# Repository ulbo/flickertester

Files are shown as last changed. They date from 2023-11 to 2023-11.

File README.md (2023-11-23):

# flickertester
Using RaspberryPi Pico to visualize flicker of LED lamps

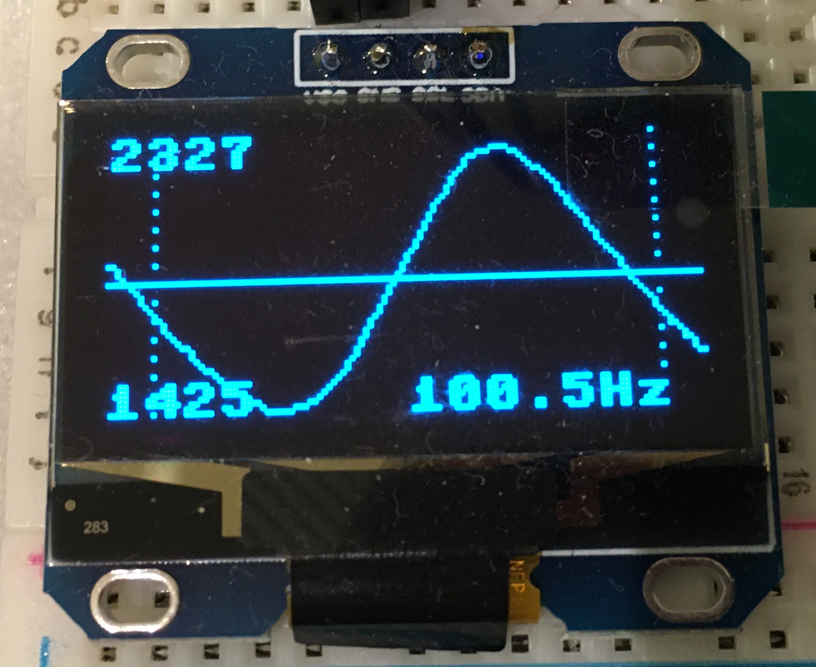
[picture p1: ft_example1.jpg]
Example


A small project for visualizing the flicker of LED lamps on a display. On the left side the minimum and maximum measured brightness value is shown, on the lower right side the calculated flicker frequency in Hertz.

Implementation is done in MicroPython on a RaspberryPi Pico using a CJMCU breakout board for the OPT101 light sensor and a SH1106 OLED display; both are available in the usual maker shops.

The analogue output value of the OPT101 is digitized by the Pico which shows the waveform on the display. Implementation is quite crude; more a proof-of-concept than a "real" device.

**Circuit**
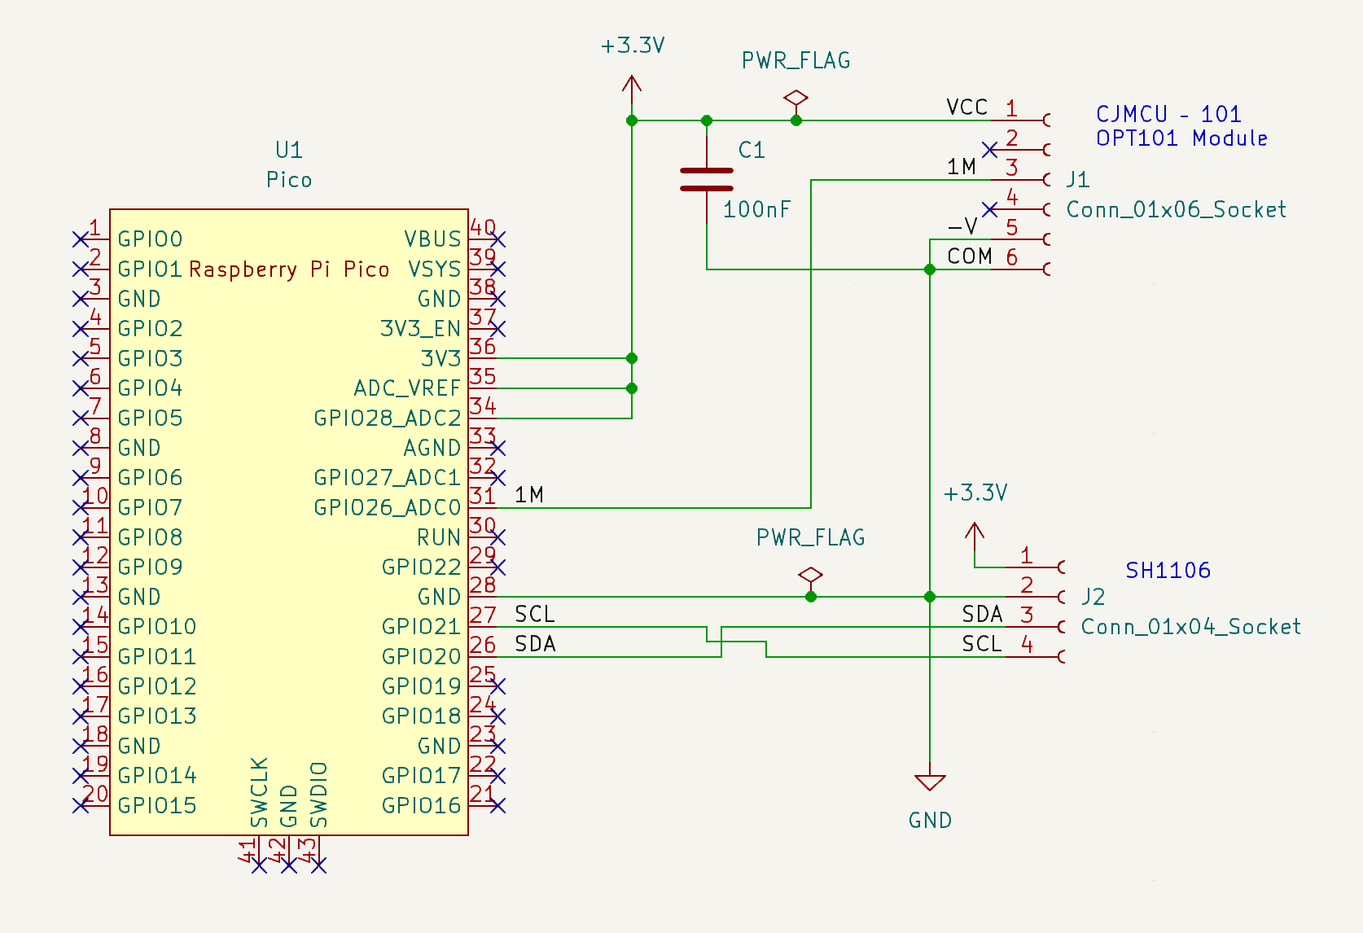
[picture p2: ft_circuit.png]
Circuit


**Breadboard**
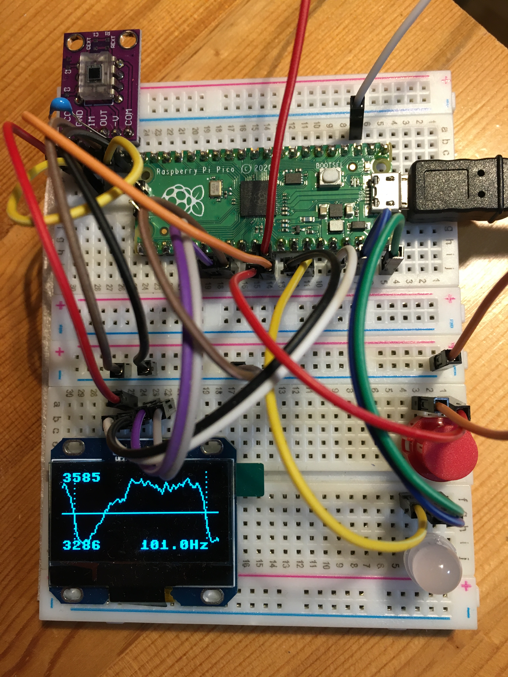
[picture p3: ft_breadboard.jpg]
Breadboard circuit


**References**

SH1106 driver: https://github.com/robert-hh/SH1106

OPT101 circuit: https://www.electroschematics.com/photodiode/

DMA code borrowed from https://iosoft.blog/2021/10/26/pico-adc-dma/

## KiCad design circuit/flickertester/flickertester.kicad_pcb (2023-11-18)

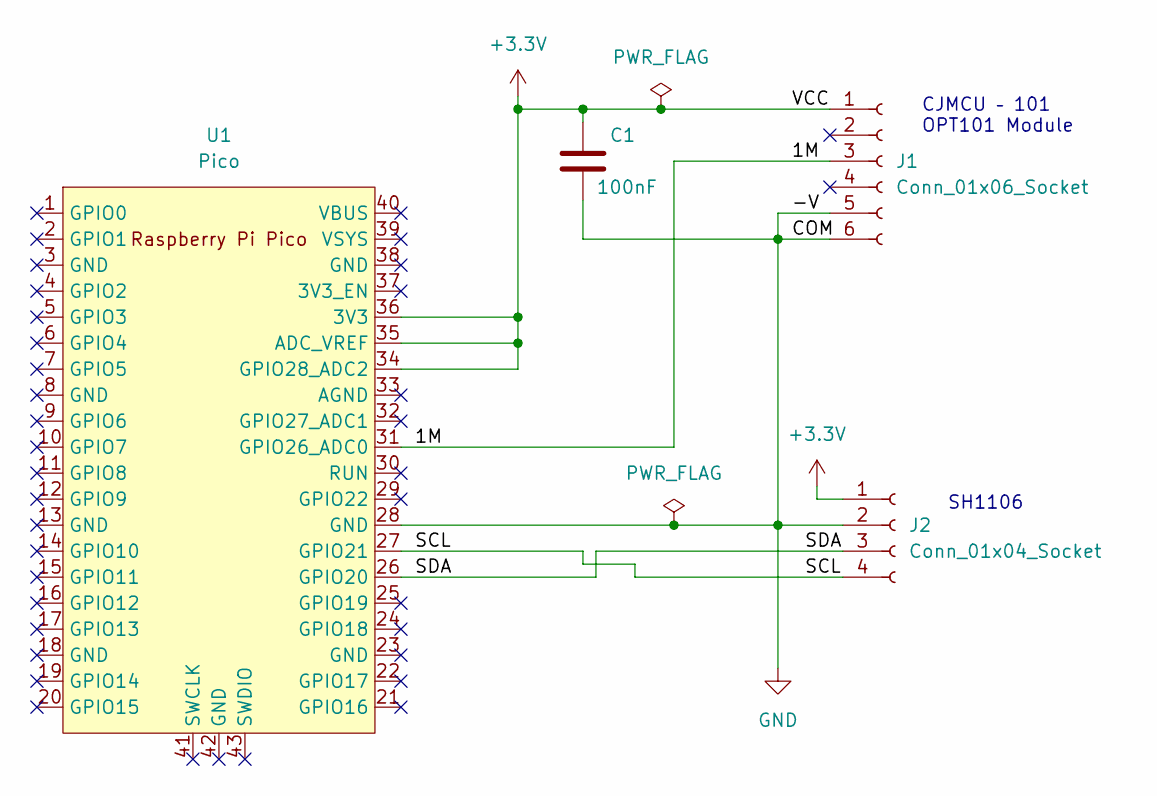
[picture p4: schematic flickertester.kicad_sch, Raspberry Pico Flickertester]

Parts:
C1: 100nF; CP_Radial_D5.0mm_P2.50mm
J1: Conn_01x06_Socket; PinSocket_1x06_P2.54mm_Vertical
J2: Conn_01x04_Socket; PinSocket_1x04_P2.54mm_Vertical
U1: Pico; RPi_Pico_SMD_TH

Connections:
+3.3V: C1.1, J1.1, J2.1, U1.34 (GPIO28_ADC2), U1.35 (ADC_VREF), U1.36 (3V3)
/1M: J1.3, U1.31 (GPIO26_ADC0)
/SCL: J2.4, U1.27 (GPIO21)
/SDA: J2.3, U1.26 (GPIO20)
GND: C1.2, J1.5, J1.6, J2.2, U1.28 (GND)

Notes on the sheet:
SH1106
CJMCU – 101 OPT101 Module

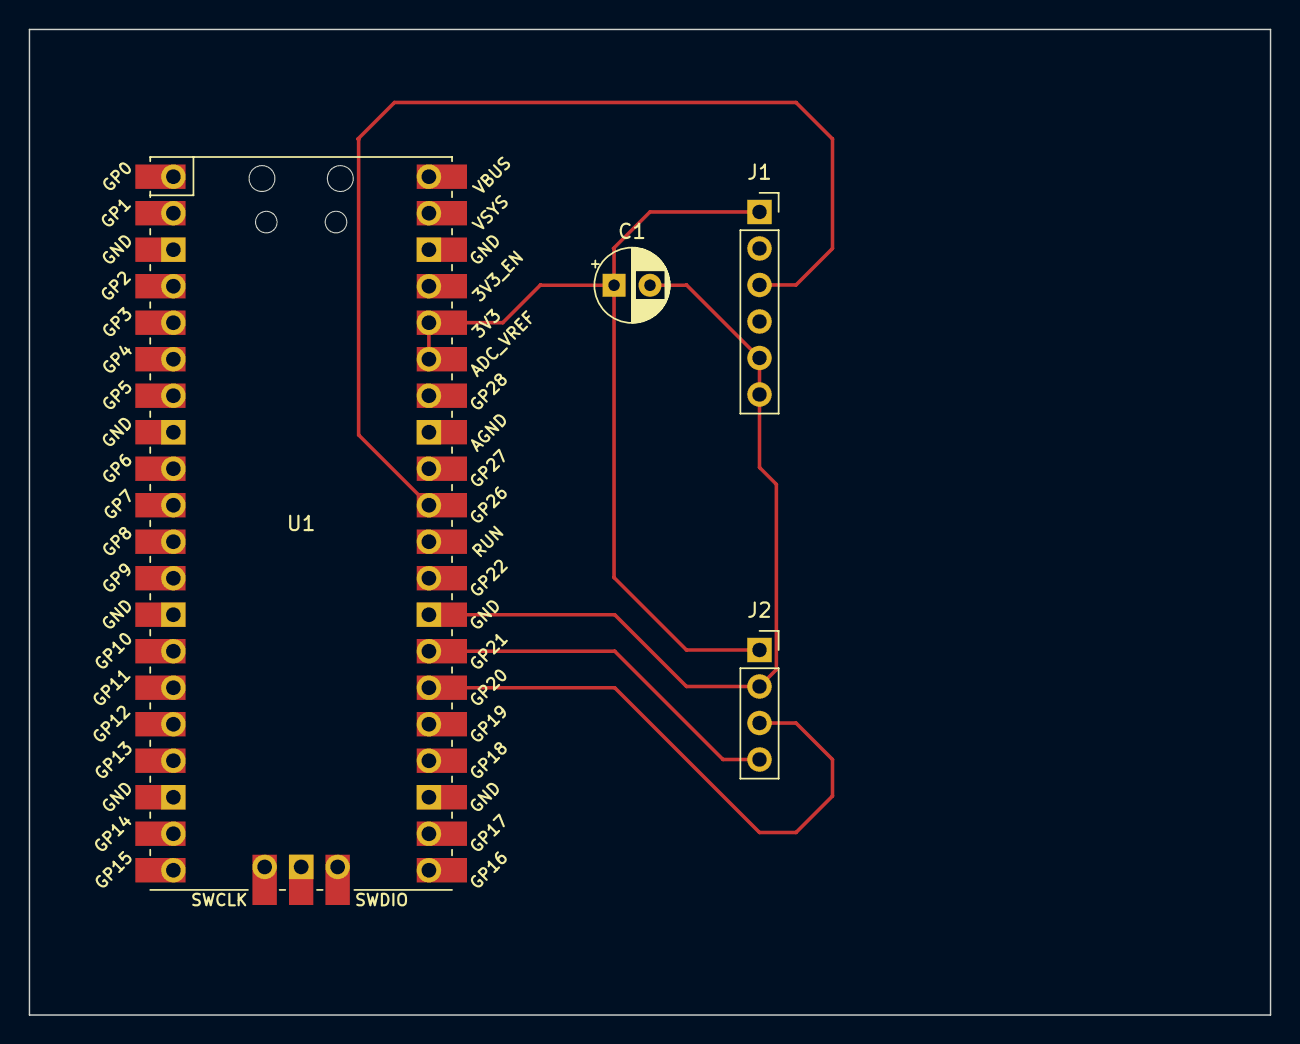
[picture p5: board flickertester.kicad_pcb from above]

Board: 2 copper layers, 86.4 x 68.6 mm, 4 parts (0 on the bottom side), 5 nets.

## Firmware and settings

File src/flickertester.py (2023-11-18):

# Display flicker curve on I2C driven SH1106 OLED display
#
# Platform: MicroPython on Raspberry Pico
# Photodiode: OPT101 (for circuit see https://www.electroschematics.com/photodiode/)
# Display: SH1106 OLED display
#
# OPT101/ADC characteristics: Min: 0V / 300 digits
#                             Max: 2.5V / 3100 digits
#
# Libraries: SH1106 driver from https://github.com/robert-hh/SH1106

from machine import I2C, ADC, Pin
from sh1106 import SH1106_I2C
import framebuf
import time, array, uctypes, rp_devices as devs

SCREEN_WIDTH  = 128         # OLED display width
SCREEN_HEIGHT = 64          # OLED display height

NSAMPLES = 1200             # number of samples taken from ADC
SAMPLING_RATE = 20000       # ADC sampling rate

# =====================================================================
# Helper functions for display graphics
# ---------------------------------------------------------------------
def pset(x: int, y: int, col:int):
    """Set pixel with upright coordinate system"""
    # pyxel.pset(x, SCREEN_HEIGHT - y, col)
    oled.pixel(x, y, 1)

# ---------------------------------------------------------------------
def line(x1: int, y1: int, x2: int, y2: int, col:int):
    """Draw line with upright coordinate system"""
    # pyxel.line(x1, SCREEN_HEIGHT - y1, x2, SCREEN_HEIGHT - y2, col)
    oled.line(x1, y1, x2, y2, 1)

# ---------------------------------------------------------------------
def vline_dot(x: int):
    "Draw a vertical dotted line"
    for y in range(0, SCREEN_HEIGHT, 4):
        oled.pixel(x, y, 1)

# ---------------------------------------------------------------------
def text(x: int, y: int, s: str, col:int):
    # pyxel.text( x, SCREEN_HEIGHT - y, s, col)
    oled.text(s, int(x), int(y))


# =====================================================================
# OLED functions
# ---------------------------------------------------------------------
# Init I2C using given Pins
def init_i2c():
    i2c = I2C(0, sda=Pin(20), scl=Pin(21), freq=400000)

    print("I2C Address      : "+hex(i2c.scan()[0]).upper()) # Display device address
    print("I2C Configuration: "+str(i2c))                   # Display I2C config
    return i2c

# ---------------------------------------------------------------------
def init_oled(i2c):
    oled = SH1106_I2C(SCREEN_WIDTH, SCREEN_HEIGHT, i2c)     # Init oled display

    # Clear the oled display in case it has junk on it.
    oled.fill(0)

    # Display is built-in upside down
    oled.flip()
    return oled

# ---------------------------------------------------------------------
def oled_demo():
    """Just to test OLED functions"""
    # Add some text
    oled.text("Raspberry Pi",5,5)
    oled.text("Pico",5,15)

    # draw something
    for i in range(5, 120, 2):
        oled.pixel(i, 50, 1)

    w = SCREEN_WIDTH-1
    h = SCREEN_HEIGHT-1

    oled.line(0, 0, w, h, 1)
    oled.line(0, h, w, 0, 1)
    x = int(w / 2)
    y = int(h / 2)
    oled.ellipse(x, y, x, y, 1)

    # Finally update the oled display so the image & text is displayed
    oled.show()

# =====================================================================
# ADC functions
# ---------------------------------------------------------------------
def init_adc(channel = 0):
    """Initialize ADC"""

    # Fetch single ADC sample
    ADC_CHAN = channel
    ADC_PIN  = 26 + ADC_CHAN

    adc = devs.ADC_DEVICE
    pin = devs.GPIO_PINS[ADC_PIN]
    pad = devs.PAD_PINS[ADC_PIN]
    pin.GPIO_CTRL_REG = devs.GPIO_FUNC_NULL
    pad.PAD_REG = 0
    time.sleep_ms(1)
    return adc


# ---------------------------------------------------------------------
def adc_get_value(adc, channel = 0):
    """Get a single measurement from ADC"""

    adc.CS_REG = adc.FCS_REG = 0
    adc.CS.EN = 1
    adc.CS.AINSEL = channel
    adc.CS.START_ONCE = 1
    val = adc.RESULT_REG

    return val


# ---------------------------------------------------------------------
def adc_get_wave(adc, nsamples, sampling_rate, channel=0):
    """Get multiple samples from ADC using DMA"""
    # idea and code borrowed from https://iosoft.blog/2021/10/26/pico-adc-dma/

    adc.CS_REG = adc.FCS_REG = 0
    adc.CS.EN = 1
    adc.CS.AINSEL = channel
    adc.CS.START_ONCE = 1

    # Multiple ADC samples using DMA
    DMA_CHAN = 0
    dma_chan = devs.DMA_CHANS[DMA_CHAN]
    dma = devs.DMA_DEVICE

    adc.FCS.EN = adc.FCS.DREQ_EN = 1
    adc_buff = array.array('H', (0 for _ in range(NSAMPLES)))
    adc.DIV_REG = (48000000 // sampling_rate - 1) << 8
    adc.FCS.THRESH = adc.FCS.OVER = adc.FCS.UNDER = 1

    dma_chan.READ_ADDR_REG = devs.ADC_FIFO_ADDR
    dma_chan.WRITE_ADDR_REG = uctypes.addressof(adc_buff)
    dma_chan.TRANS_COUNT_REG = nsamples

    dma_chan.CTRL_TRIG_REG = 0
    dma_chan.CTRL_TRIG.CHAIN_TO = DMA_CHAN
    dma_chan.CTRL_TRIG.INCR_WRITE = dma_chan.CTRL_TRIG.IRQ_QUIET = 1
    dma_chan.CTRL_TRIG.TREQ_SEL = devs.DREQ_ADC
    dma_chan.CTRL_TRIG.DATA_SIZE = 1
    dma_chan.CTRL_TRIG.EN = 1

    while adc.FCS.LEVEL:
        x = adc.FIFO_REG

    adc.CS.START_MANY = 1

    # wait for DMA to finish
    while dma_chan.CTRL_TRIG.BUSY:
        time.sleep_ms(10)
    adc.CS.START_MANY = 0
    dma_chan.CTRL_TRIG.EN = 0

    # print(adc_buff)
    return adc_buff

# ---------------------------------------------------------------------
def scale(x1: float, x2: float, y1: float, y2: float) -> tuple[float]:
    """Calculate gain (slope) and offset (intersection with x-axis)
       of linear equation from two points (x1, y1), (x2, y2).
       from
    """
    gain = (y2 - y1) / (x2 - x1)
    offset = (y1*x2 - y2*x1) / (x2 - x1)

    return (gain, offset)

# ---------------------------------------------------------------------
def find_period(wv: list[int]) -> tuple:
    """
    Find first, mid and last index belonging to one period of wave {wv}.
    :param wv: wave as list of integers

    :return:    tuple of indices in {wv}: (first, middle, last) sample
                of one period
    """

    wv_max = max(wv)
    wv_min = min(wv)

    average = (wv_max + wv_min) / 2.
    trigger_level = (wv_max - average) * 0.3
    first = mid = last = 0
    threshold = average - trigger_level
    # print(wv_min, wv_max, trigger_level)

    # initialize: search for falling edge first
    for i, y in enumerate(wv):

        if y < threshold:
            first = i
            threshold = average + trigger_level
            break

    # search for i where (y - {average}) changes polarity
    for i in range(first, len(wv)):
        y = wv[i]

        if y > threshold:
            first = i
            threshold = average - trigger_level
            break

    # search for falling edge
    for i in range(first, len(wv)):
        y = wv[i]

        if y < threshold:
            mid = i
            threshold = average + trigger_level
            break

    # search for rising edge again
    for i in range(mid, len(wv)):
        y = wv[i]

        if y > threshold:
            last = i
            break

    return (first, mid, last)

# ---------------------------------------------------------------------
def filter_wave(wave: list[int]) -> list[int]:
    """Filter algorithm designed using http://t-filter.engineerjs.com
    Sampling rate: 20000 Hz
    Specs:
        * 0 Hz - 2000 Hz
        gain = 1
        desired ripple = 5 dB
        actual ripple = 4.024246464355393 dB

        * 6000 Hz - 10000 Hz
        gain = 0
        desired attenuation = -60 dB
        actual attenuation = -60.309797420786424 dB
    """

    FILTER_TAPS = [
            0.007368171996559226,
            0.04974402650118188,
            0.1447129657129954,
            0.2573965885895257,
            0.30915399294515716,
            0.2573965885895257,
            0.1447129657129954,
            0.04974402650118188,
            0.007368171996559226
    ]

    wave_out = []

    for i in range(len(wave)):
        # print(f"{wave[i]}:", end="   ")
        val = 0.
        for t in range(len(FILTER_TAPS)):
            if i + t < len(wave):
                val += wave[i + t] * FILTER_TAPS[t]
                # print(f"{val}", end=" ")

        wave_out.append(int(val))
        # print(f"   [{val}]")

    return wave_out

# ---------------------------------------------------------------------
def display_wave(wave: list[int],
                 sampling_rate: int,
                 screen_width: int,
                 screen_height: int):

    if True:
        # denoise wave
        wv = filter_wave(wave)
        
        # The 9th order FIR filter distorts the last 9 samples of the waveform,
        # so we cut these here.
        wv = wv[0:len(wv)-10]
    else:
        wv = []

        for i, v in enumerate(wave):
            if i < 1:
                wv.append(int(v))
            else:
                wv.append(int((v + prev) / 2.))

            prev = v


    # calculate period of wave
    n1, n2, n3 = find_period(wv)

    # emergency exit if flicker frequency too high
    if n3 - n1 < 3:
        # for n in wv:
        #     print(n)
        print(f"Frequency too high: n1={n1} n3={n3}")
        return

    # calculate part of wave that will be displayed on screen
    # we will show one full period of wave plus about 10% at each side

    # calculate factors to scale wave to fit in screen
    screen_range_x = n3 - n1
    padding = 0.1
    screen_x1 = int(n1 - screen_range_x * padding)
    screen_x2 = int(n3 + screen_range_x * padding)
    screen_scaling = (screen_x2 - screen_x1) / screen_width

    ymin = min(wv)
    ymax = max(wv)
    screen_low = screen_height * 0.05   # lowest value in screen coordinates for wave
    screen_high = screen_height * 0.95  # highest value

    gain, offset = scale(ymin, ymax, screen_low, screen_high)

    # wv_screen = []
    # for i in range(screen_width):
    #     wv_screen.append(wv[int(i * screen_scaling + screen_x1)] * gain + offset)
    wv_screen = [int(wv[int(i * screen_scaling + screen_x1)] * gain + offset) for i in range(screen_width)]

    # calculate index of first and last x value of period
    marker1 = int((n1 - screen_x1) / screen_scaling)
    marker2 = screen_width - int((screen_x2 - n3) / screen_scaling)

    frequency = sampling_rate / (n3 - n1)

    # scale average to match wave and show it
    average = (min(wv) + max(wv)) / 2.
    average = int(average * gain + offset)
    line(0, average, screen_width, average, 1)

    # show first and last x value of period
    vline_dot(marker1)
    vline_dot(marker2)

    # draw wave
    for x in range(screen_width):
        y = wv_screen[x]
        
        if x == 0:
            pset(x, y, 10)
        else:
            line(x_prev, y_prev, x, y, 10)
            
        x_prev = x
        y_prev = y

    # text(0, SCREEN_HEIGHT - 10, f"{round(100*(ymax - ymin) / ymax)}%", 1)
    text(0, 0, f"{ymax}", 1)
    text(0, SCREEN_HEIGHT - 10, f"{ymin}", 1)
    text(SCREEN_WIDTH / 2, SCREEN_HEIGHT - 10, f"{round(frequency, 1):5.1f}Hz", 1)

# ---------------------------------------------------------------------
def main():

    global oled
    oled = init_oled(init_i2c())
    adc = init_adc()

    while(1):

        # measure light intensity
        wv = adc_get_wave(adc, NSAMPLES, SAMPLING_RATE)

        maximum = max(wv)
        minimum = min(wv)
        avg = int((maximum + minimum) / 2.)

        oled.fill(0)

        # if we have no flicker, then display average light intensity
        # otherwise display wave
        if maximum - minimum < 200:
            oled.text(f"{avg}", 5, 24)
        else:
            display_wave(wv, SAMPLING_RATE, SCREEN_WIDTH, SCREEN_HEIGHT)

        # update the oled display so image & text are displayed
        oled.show()


if __name__ == '__main__':
    main()

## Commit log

2023-11-18 added: source, circuit data and example images
    [flickertester.kicad_pcb, flickertester.kicad_sch]
2023-11-23 added: circuit image
